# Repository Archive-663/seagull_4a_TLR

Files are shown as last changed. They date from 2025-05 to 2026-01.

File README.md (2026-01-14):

# Lot no. 020 | Seagull 4a Accessories

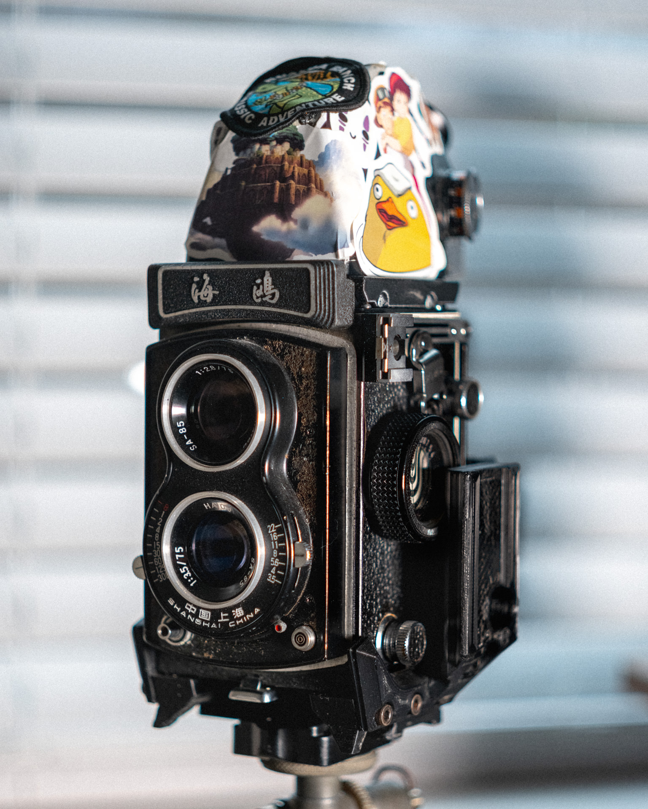
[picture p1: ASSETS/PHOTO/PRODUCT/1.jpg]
productShot001


### In this repository:
- [GFX Strap Lug Locks](https://github.com/Archive-663/seagull_4a_TLR/tree/main/seagull_4a_GFXstrapLug)
- [Jawbone Half Cage](https://github.com/Archive-663/seagull_4a_TLR/tree/main/Jawbone%20Half%20Cage)
- [Viewfinder](https://github.com/Archive-663/seagull_4a_TLR/tree/main/Viewfinder)

### Background Story:
This camera was my first foray into Medium Format. It's a wonderfully cheap, but effective 6x6 camera. While I'm okay using it as it, I felt there were a few things that could be improved. So I added a half cage with standard 1/4-20 mounts, Arca Swiss plate, and common film reminder dials. I could not find camera strap lugs so I used my GFX camera strap lugs with 3d printed locks to allow me to use it on the Seagull. I've since found out that the Canon EOS M (original) camera strap lugs work on the Seagull with little to no modification.

### Help support Archive 663 with a dontation or monthly sub



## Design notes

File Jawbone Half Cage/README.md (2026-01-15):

## Half Cage for Seagull 4A-103	

halfCageSeagull4A001a
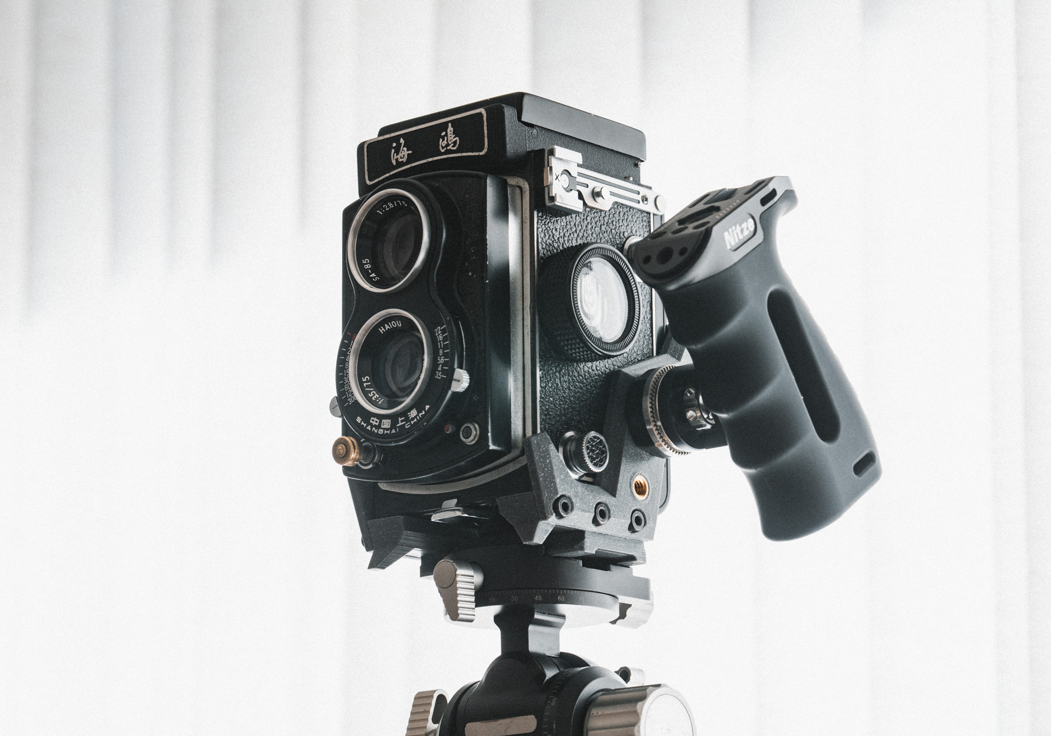
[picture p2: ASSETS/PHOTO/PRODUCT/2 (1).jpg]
halfCageSeagull4A001

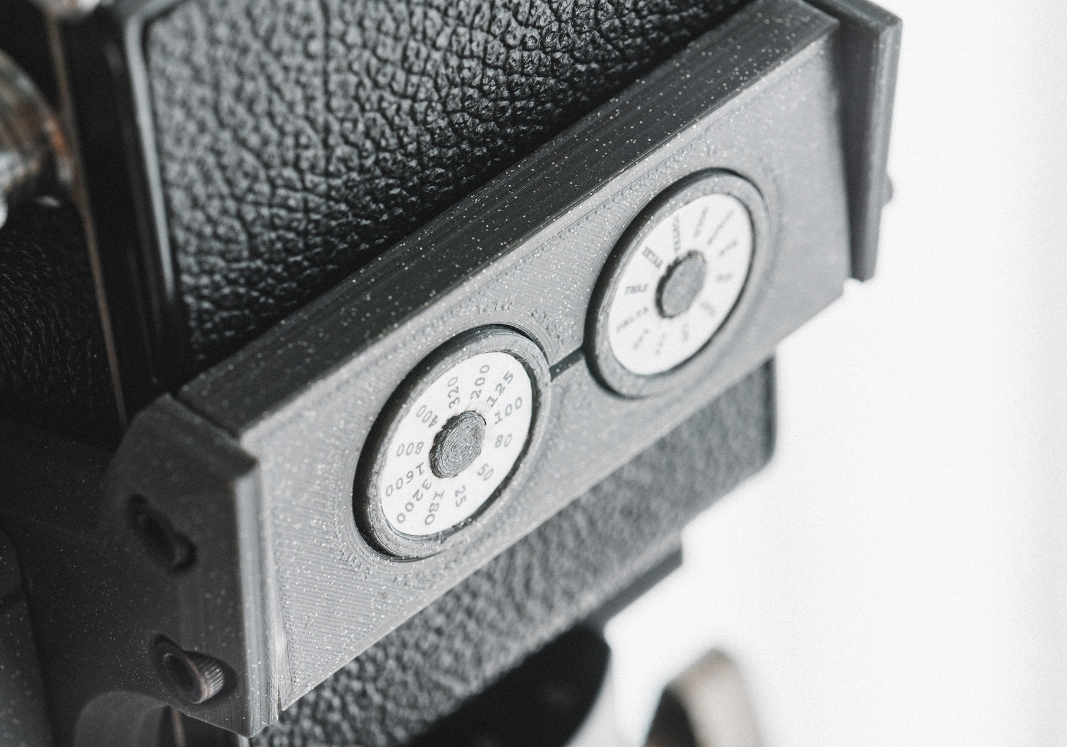
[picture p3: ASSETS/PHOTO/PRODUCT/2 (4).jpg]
halfCageSeagull4A004


### Features:
- Arca-Swiss compatible rail.
- Customizable & Removeable 90 degree Arca-Swiss rail.
- Common dilm reminder dials
- 3x 1/4-20 mounting points for expandability

### What you'll need:
- 1x 1/4-20 x 3/8" hex drive pan head screw
- 2x 1/4-20 x 1/2" hex drive pan head screw
- 3x 1/4-20 x 7mm Heatset Threaded Insert
- 6x M1.6 x 5mm self tapping or machine screws
- 10x M4 x 12mm Hex Cap Machine Screw
- 10x M4 x 8mm Heatset Threaded Insert
- 1x Soldering Iron or Heat Set Insert Jig
- Assortment of mini files

### What would be helpful:
- M4 drill bit
- M5.3 drill bit
- 1/4 drill bit

### Printing help:
Filament recommendation:
- ABS

Normally, I would recommend PETG but it's pretty bad with impacts.

Generally, all my designs have chamfers on the print face of the STL. You can reference the supplied 'printOrientation' .3mf files for suggested print orientation.

### Assembly help:
Drill holes to their correct tap size before tapping.
- M4 heatset inserts require M5.3 bore.
- 1/4-20 heatset inserts require a 8.8ish mm bore.

Use the attached Affinity Designer .afdesign file to edit and print your film reminder dial labels. Affinity Designer is now free to use so sign up and grab it! https://www.affinity.studio/download

Please view the _assembly.stp file for help in parts orientation. If you do not have a CAD program, download FreeCAD to view the assembly file and better understand how it should assemble. If using FreeCAD, the naming conventions should carry over and you will be able to see which lens element you need from the various smartphone lenses. (Verified in FreeCAD 0.18) If using something like Solid Edge open the file as an assembly to retain the names of the parts.

### Help support Archive 663 with a dontation or monthly sub



### Samples:

halfCageSeagull4ASample001
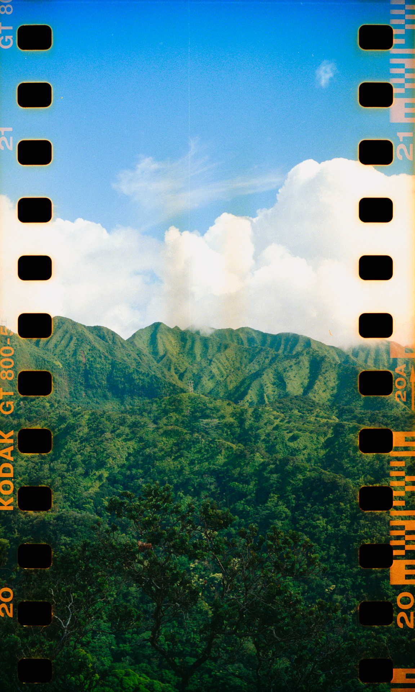
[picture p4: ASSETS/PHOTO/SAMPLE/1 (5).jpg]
halfCageSeagull4ASample002

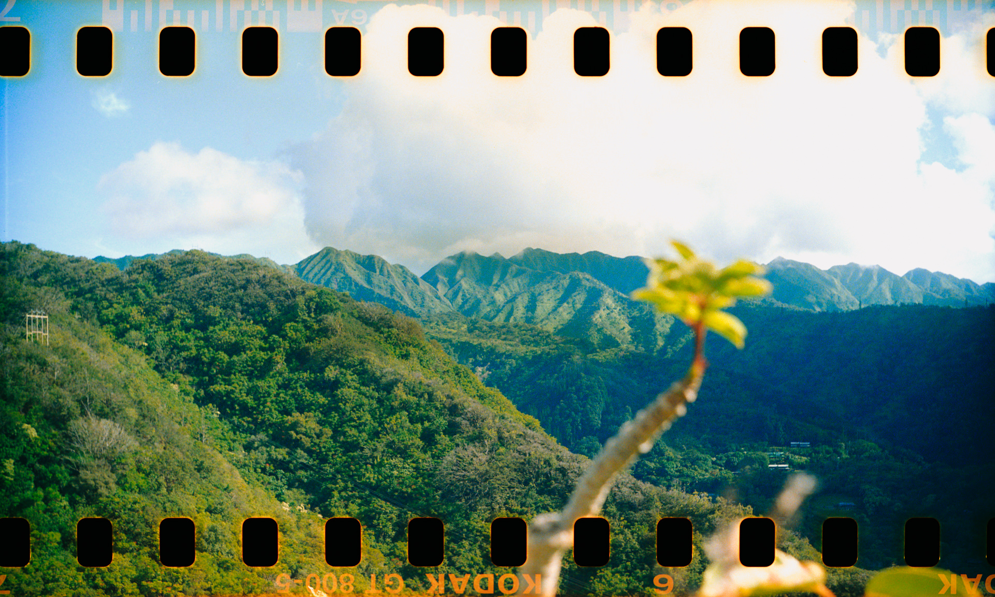
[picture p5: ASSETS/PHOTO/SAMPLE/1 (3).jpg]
halfCageSeagull4ASample003

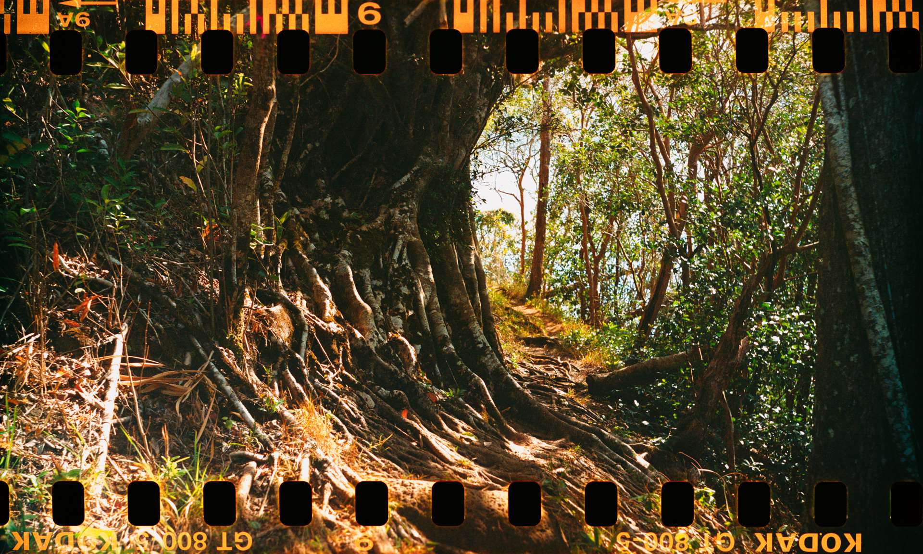
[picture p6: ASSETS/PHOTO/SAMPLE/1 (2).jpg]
halfCageSeagull4ASample004


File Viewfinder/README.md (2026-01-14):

## Viewfinder Adapter for Seagull 4A-103	

halfCageSeagull4A001

### Features:
- Uses factory waist level finder screws
- Allows you to adapt any viewfinder that will fit onto the Seagull 4A body

### What you'll need:
- 4x M1.6 x 5mm self tapping or machine screws
- 4x Original viewfinder mounting screws
- Assortment of mini files

### What would be helpful:
- M1.6 Drill bit
- M1.6 Tap
- M1.4 Drill bit for pilot tap hole

### Printing help:
Filament recommendation:
- ABS
-PETG

Generally, all my designs have chamfers on the print face of the STL. You can reference the supplied 'printOrientation' .3mf files for suggested print orientation.

### Assembly help:
Drill holes to their correct tap size before tapping.
- M1.6 threads require M1.4 bore.

Please view the _assembly.stp file for help in parts orientation. If you do not have a CAD program, download FreeCAD to view the assembly file and better understand how it should assemble. If using FreeCAD, the naming conventions should carry over and you will be able to see which lens element you need from the various smartphone lenses. (Verified in FreeCAD 0.18) If using something like Solid Edge open the file as an assembly to retain the names of the parts.

### Bring your own viewfinder:
Download the STEP files and modify the adapter to fit your viewfinder in the CAD package of your choice.

### Help support Archive 663 with a dontation or monthly sub



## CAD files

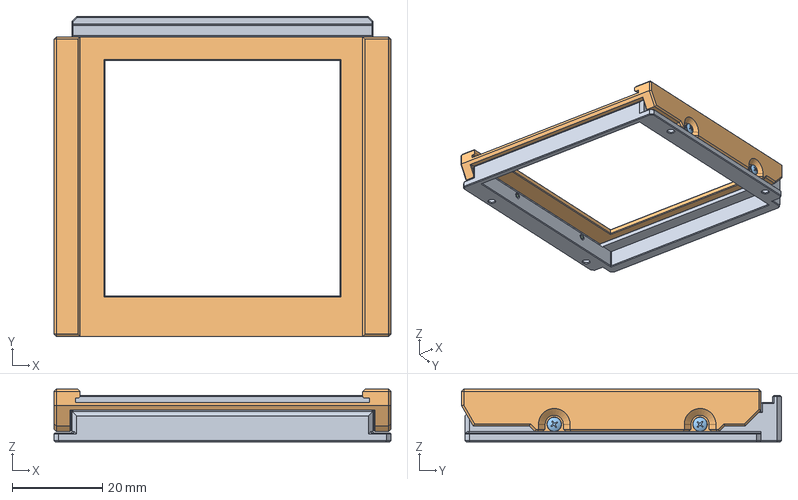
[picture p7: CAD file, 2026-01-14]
Viewfinder/STEP/seagull_4A104_viewFinder_hasselblad-52051_assembly.stp
74.5 x 70.8 x 11.7 mm
seagull4A_viewFinder
seagull4A_viewFinder_topHasselblad45
M1.6_panHead_5mm x 4

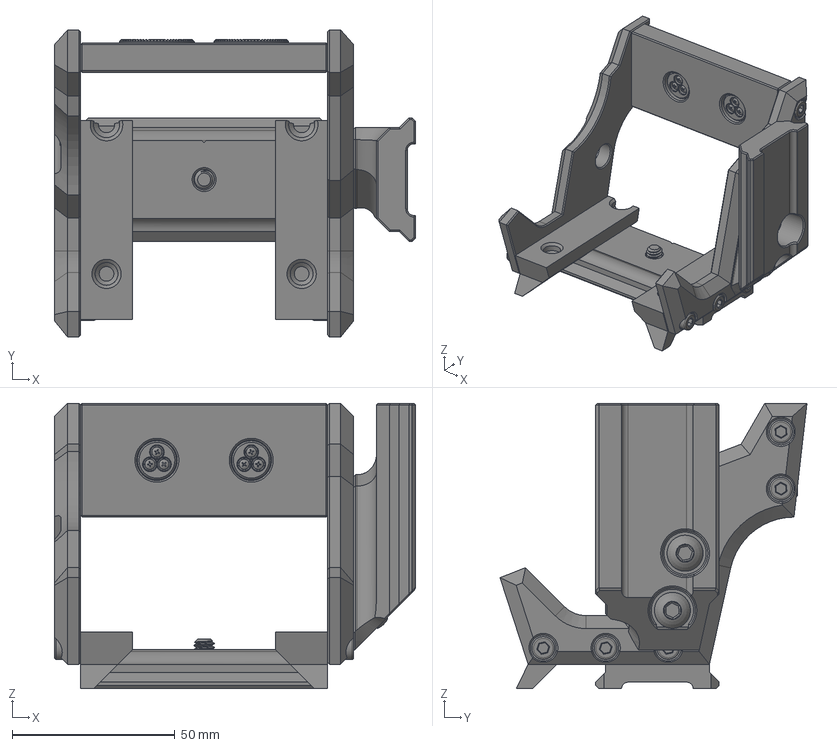
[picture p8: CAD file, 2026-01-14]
Jawbone Half Cage/STEP/seagull_4A104_jawboneHalfCage_assembly.stp
111.0 x 94.4 x 87.8 mm
seagull4A_l-Bracket_focus_002
M4_heatSetInsert_8mm x 10
seagull4A_l-Bracket_winder_002
seagull4A_l-Bracket_arcaSwissBase_002
seagull4A_l-Bracket_brace_002
seagull4A_l-Bracket_filmDial_002 x 2
seagull4A_l-Bracket_filmDial_back_002 x 2
seagull4A_l-Bracket_arcaSwissSideBase_002
M4_hexCapHead_12mm x 10
1_4-20_8-8mm_x_7mm_heatSet x 3
1_4-20_buttonHead_12mm x 2
1_4-20_buttonHead_9.35mm
M1.6_panHead_5mm x 3
M1.6_panHead_5mm_mir x 3

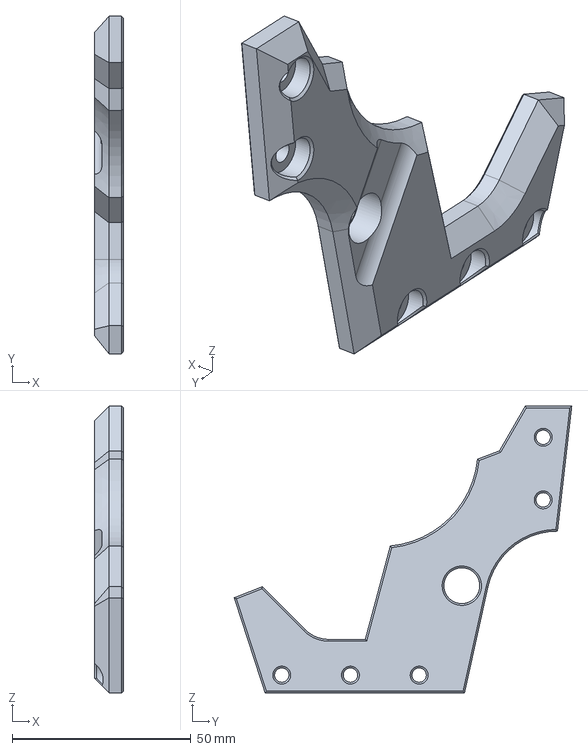
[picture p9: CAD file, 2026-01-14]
Jawbone Half Cage/STEP/seagull4A_l-Bracket_winder_002.stp
8.00 x 94.4 x 80.3 mm

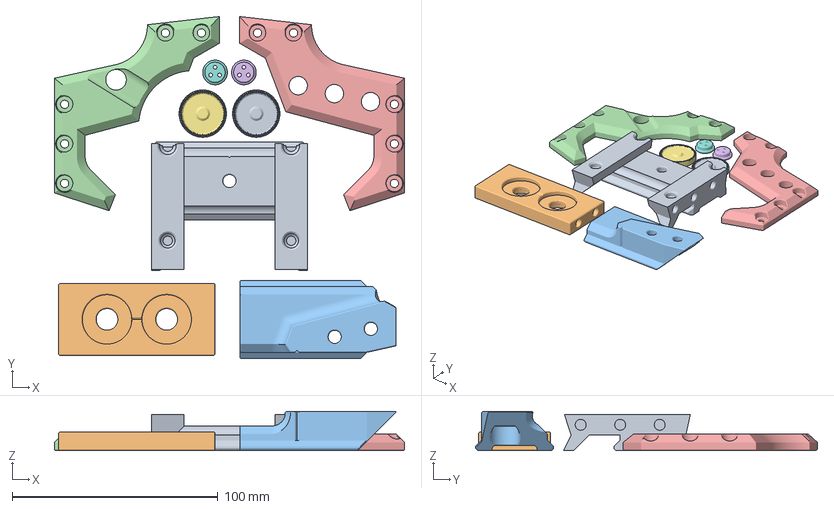
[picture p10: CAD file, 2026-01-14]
Jawbone Half Cage/STL/seagull4A_jawboneHalfCage_printOrientation.3mf
170.3 x 166.2 x 19.0 mm
seagull4A_l-Bracket_arcaSwissBase_002.stl
seagull4A_l-Bracket_brace_002.stl
seagull4A_l-Bracket_arcaSwissSideBase_002.stl
seagull4A_l-Bracket_winder_002.stl
seagull4A_l-Bracket_focus_002.stl
seagull4A_l-Bracket_filmDial_back_002.stl
seagull4A_l-Bracket_filmDial_002.stl
seagull4A_l-Bracket_filmDial_back_002.stl(1)
seagull4A_l-Bracket_filmDial_002.stl(1)

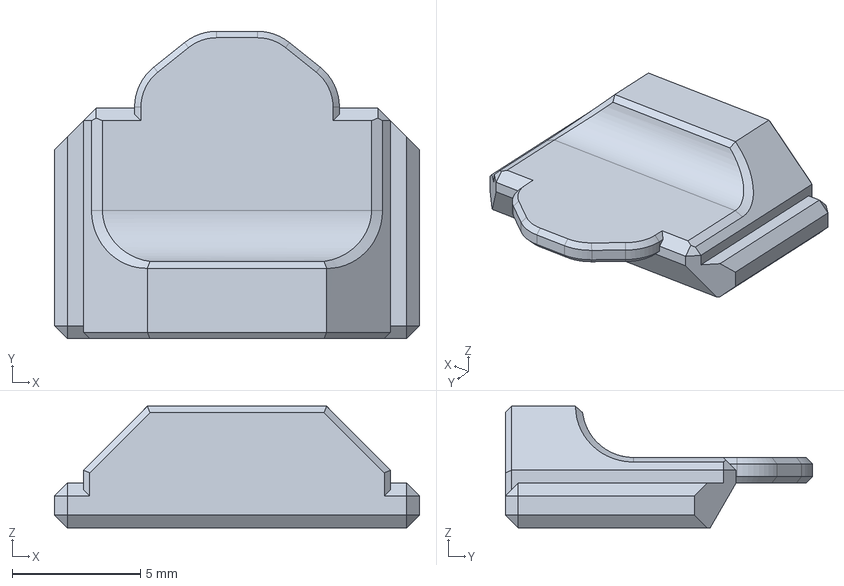
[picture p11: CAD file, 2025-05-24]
seagull_4a_GFXstrapLug/STEP/seagull4A_GFXcameraStrapLug_base.stp
14.2 x 12.0 x 4.75 mm

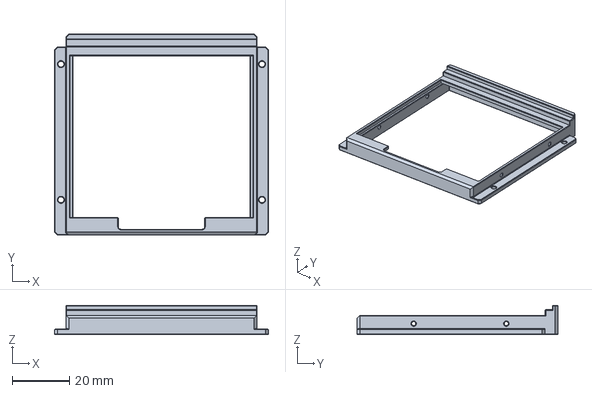
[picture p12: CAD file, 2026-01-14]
Viewfinder/STEP/seagull_4A104_viewFinder_base.stp
74.5 x 70.0 x 10.2 mm

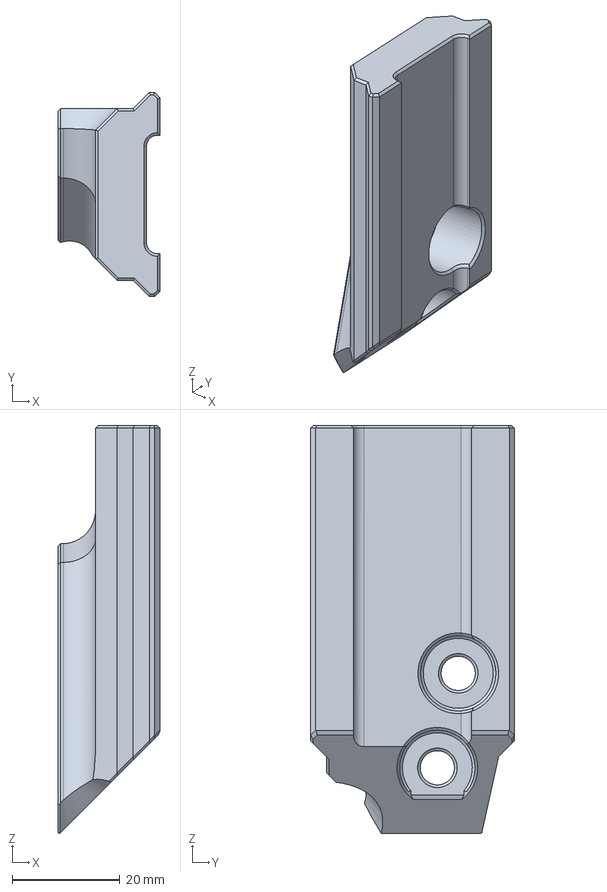
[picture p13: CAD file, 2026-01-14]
Jawbone Half Cage/STEP/seagull4A_l-Bracket_arcaSwissSideBase_002.stp
19.0 x 38.0 x 75.9 mm

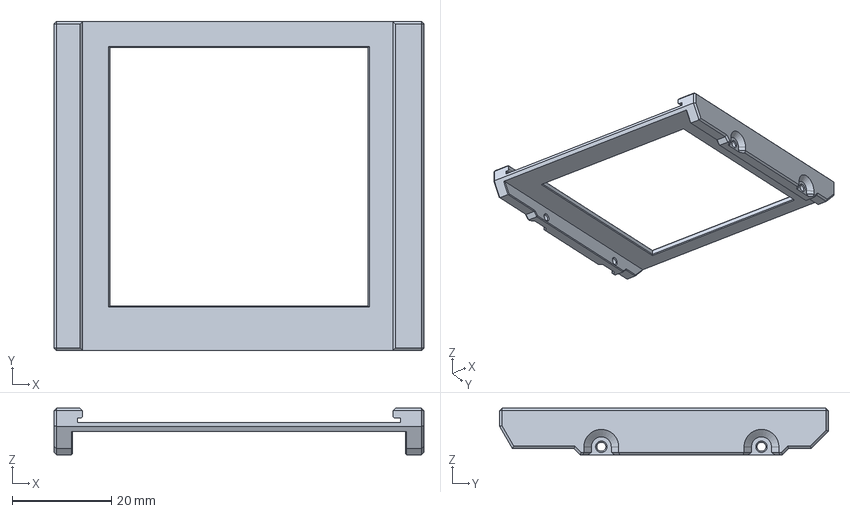
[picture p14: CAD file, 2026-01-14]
Viewfinder/STEP/seagull_4A104_viewFinder_hasselblad-52051.stp
74.5 x 66.3 x 9.40 mm

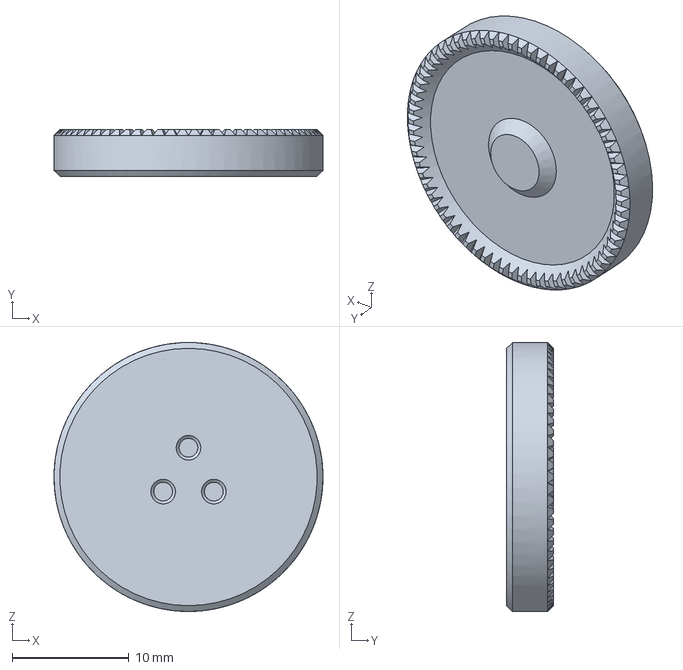
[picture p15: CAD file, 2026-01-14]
Jawbone Half Cage/STEP/seagull4A_l-Bracket_filmDial_002.stp
23.0 x 4.00 x 23.0 mm

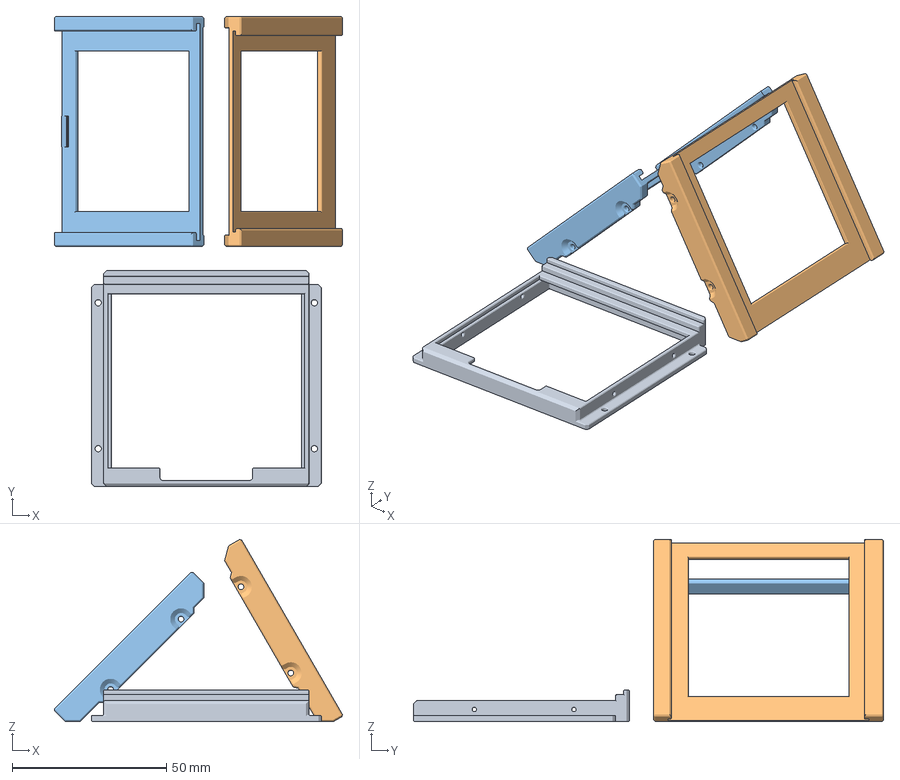
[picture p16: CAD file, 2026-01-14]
Viewfinder/STL/seagull4A_viewFinder_printOrientation.3mf
93.3 x 152.2 x 58.9 mm
seagull4A_viewFinder.stl
seagull4A_viewFinder_topHasselblad45.stl
seagull4A_viewFinder_top.stl

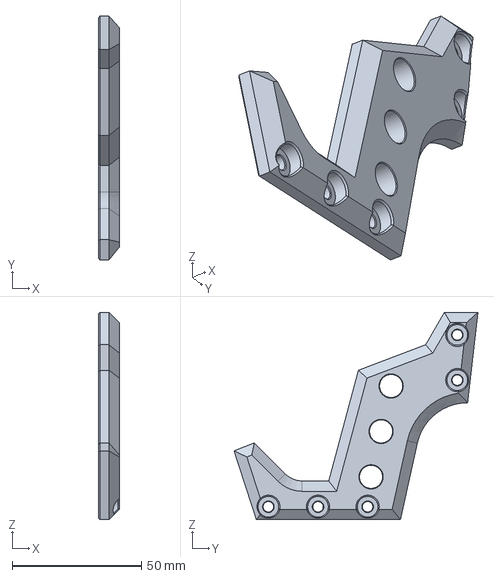
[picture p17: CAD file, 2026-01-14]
Jawbone Half Cage/STEP/seagull4A_l-Bracket_focus_002.stp
8.00 x 94.4 x 80.3 mm

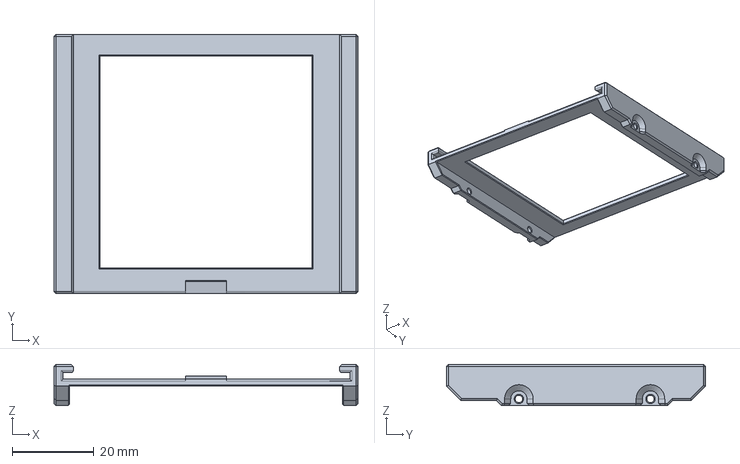
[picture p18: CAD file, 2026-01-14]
Viewfinder/STEP/seagull_4A104_viewFinder_kowaSix.stp
74.5 x 63.5 x 10.1 mm

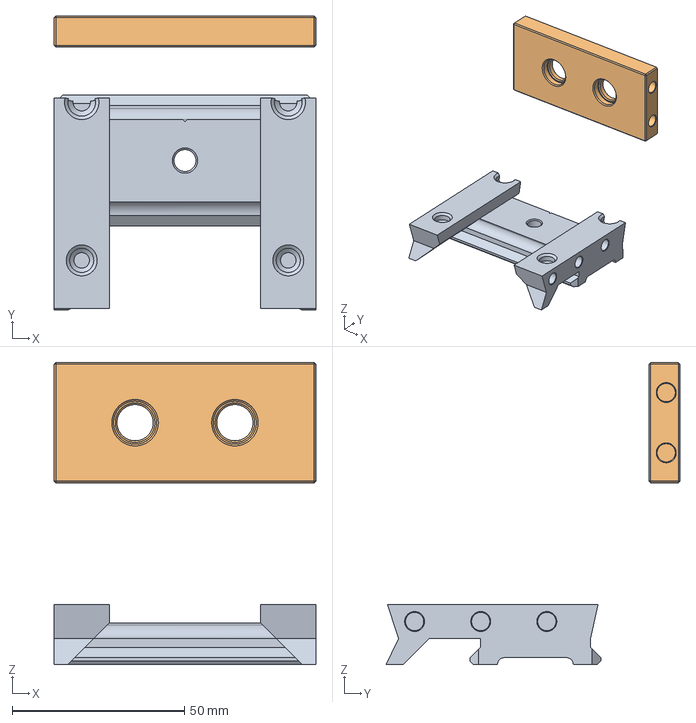
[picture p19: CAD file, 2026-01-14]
Jawbone Half Cage/STEP/seagull4A_l-Bracket_brace_002.stp
76.0 x 85.4 x 87.8 mm
seagull4A_l-Bracket_arcaSwissBase_002
seagull4A_l-Bracket_brace_002

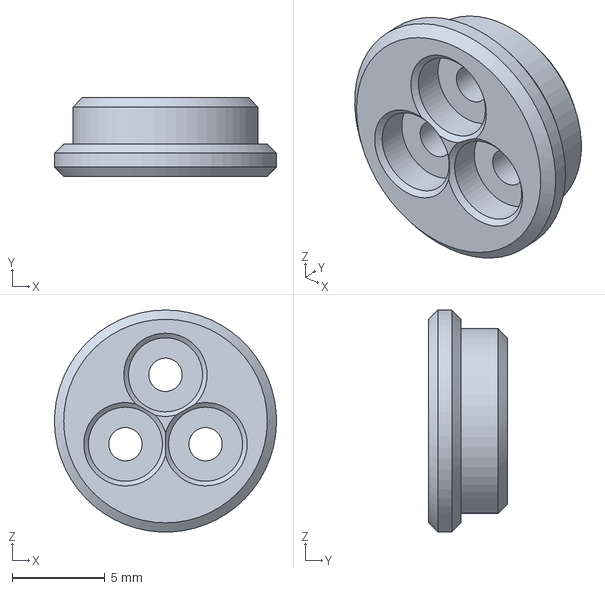
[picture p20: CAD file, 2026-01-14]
Jawbone Half Cage/STEP/seagull4A_l-Bracket_filmDial_back_002.stp
12.0 x 4.25 x 12.0 mm

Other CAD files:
Viewfinder/STL/seagull4A_viewFinder.stl
Viewfinder/STL/seagull4A_viewFinder_topHasselblad45.stl
Viewfinder/STL/seagull4A_viewFinder_top.stl
Jawbone Half Cage/STEP/seagull4A_l-Bracket_arcaSwissBase_002.stp
Jawbone Half Cage/STL/seagull4A_l-Bracket_arcaSwissBase_002.stl
Jawbone Half Cage/STL/seagull4A_l-Bracket_arcaSwissSideBase_002.stl
Jawbone Half Cage/STL/seagull4A_l-Bracket_brace_002.stl
Jawbone Half Cage/STL/seagull4A_l-Bracket_filmDial_002.stl
Jawbone Half Cage/STL/seagull4A_l-Bracket_filmDial_back_002.stl
Jawbone Half Cage/STL/seagull4A_l-Bracket_focus_002.stl
Jawbone Half Cage/STL/seagull4A_l-Bracket_winder_002.stl
seagull_4a_GFXstrapLug/STL/seagull4A_GFXcameraStrapLug_base.stl
